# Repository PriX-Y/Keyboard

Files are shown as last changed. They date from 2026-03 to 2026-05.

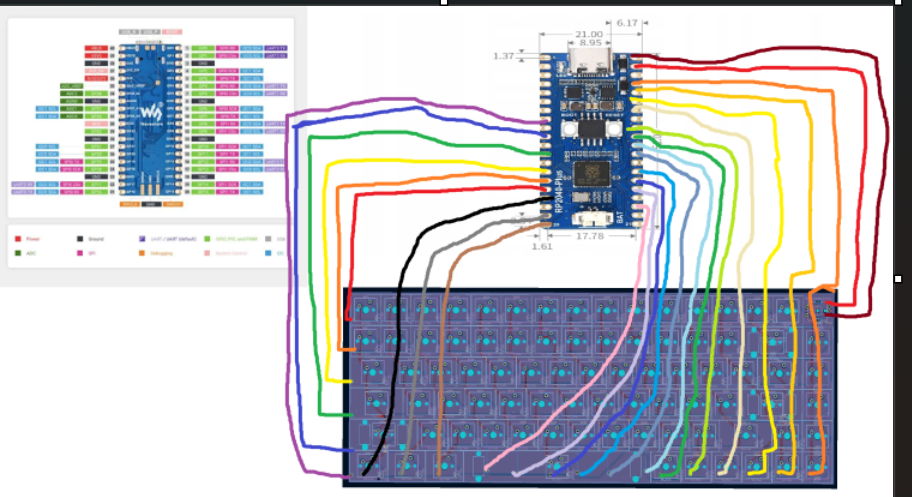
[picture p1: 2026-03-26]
Wiring Diagram.png

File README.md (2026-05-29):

# Befor. Im from Poland and im dont speak english very well , dont rate grammer :)

# HI. there is my keyboard
I made this becuse i need keyboard. my actualy keyboard is 12 years: cosaco keyboard what i need use hot glue to repeir what.

IMG_20260326_175041831_MFNR
IMG_20260326_175053504_MFNR

it still work but Bro . you see how this look , i dont say its bad keyboard for me is fine but i wanna make something own what i be use for next years.

# So there is my PKSBoard ( i dont have idea for name) 

1776988882284-g3whwp

**Note** im finnaly dont use case becuse i dont have budget left for printing legion

**It base on most simple things but becuse i wanna clean 65%+ i need to make Mcu and Key PCB separate**
 on key pcb you dont see rp2040 its becuse i separte it and is why pick 2.54mm right angle , cable, 

Zrzut ekranu 2026-03-27 213238

Zrzut ekranu 2026-03-27 213307

Zrzut ekranu 2026-02-13 215402

-**MCU:** RP2040-Plus ,  Everyone know wha t mcu is this.

-**PCB:** My own project , Is **65%** size keyboard but i add Function button and Rotery Encoder
Zrzut ekranu 2026-03-26 210054
old version
Zrzut ekranu 2026-03-14 180553

-**Switch:** Akko V3 creamy blue is one of best budget switch on the world. its tactical so is silent 
but you fell click

-**Keycaps.** any random chepest keycaps what i can find to fit in budget

-**Stablizators:** for keycaps

-**cable** just cable
there is cart

Zrzut ekranu 2026-03-26 194902

-**Diods:** i pick that becuse i have footprint only for this one

-**Connector:** to conect it its why is right angle
there is cart from tme

Zrzut ekranu 2026-03-24 231726

**Case:** is simple case what i made in Fusion , im not skilled in this so is why is a simple.

Zrzut ekranu 2026-03-23 025524

# **i use programs:**

**Kicad:** For PCB
**Autodesk** fusion: For 3D modeling
**Paint:** for diagram
**Google Docs:** For BOM
**Cursor:** for code

is all i spend aorund 20h on buldi this becuse i spend aorund 7h mcu what i finnaly dont buldi becuse cost. i have all in blueprint site so is why i dont have jounary here. finally my keyboard for me personal is good ( i be happy if it get aproved) 

# btw im pass this 

# there is one thing what left: BOM ( without link there, link verison is in folder)


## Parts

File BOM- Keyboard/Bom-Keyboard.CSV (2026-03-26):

Swicht Akko v3 creamy blue 45 pack | x2 | 29.12$ (14.56$ x2) | aliexprees | https://pl.aliexpress.com/item/1005006382591392.html?mp=1
Keyboard Pcb + ship + tax | x1 | 40.42$ | Jbpcb | https://jlcpcb.com/
1N4148W Diodes, Headers, Shipping | x1 | 10.31$ | tme.eu | https://www.tme.eu/pl/
rassbery pico - rp2040 plus | x1 | 6.76$ | aliexprees | https://pl.aliexpress.com/item/1005005655604927.html?mp=1
keyscaps stabilizator | x1 | 5.78$ | aliexprees | https://pl.aliexpress.com/item/1005001686299616.html?mp=1
keycaps - purple + dark | x1 | 4.01$ | aliexprees | https://pl.aliexpress.com/item/1005011904232892.html?mp=1
cable 20 pack F to F | x2 | 2.70$ (1.35$ x2) | aliexprees | https://pl.aliexpress.com/item/1005007138874742.html?mp=1
Total Cost: $99.10
I ask for 100$ if something left i give it back

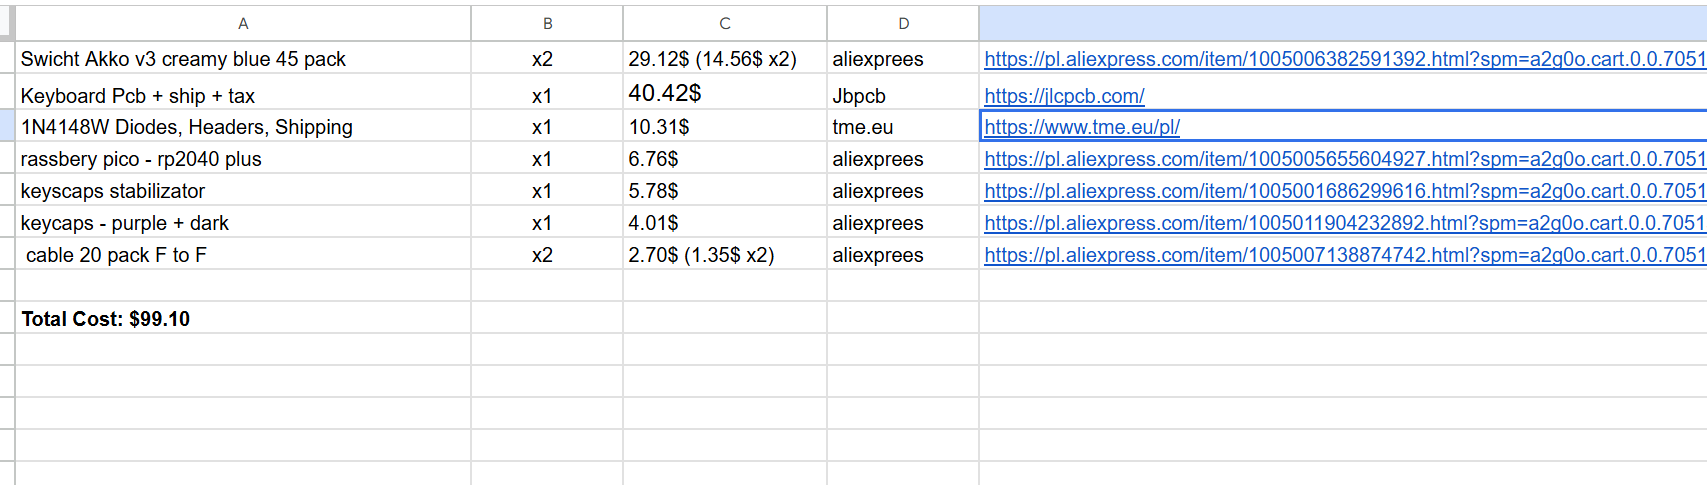
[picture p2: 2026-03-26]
BOM- Keyboard/BOM-Image.png

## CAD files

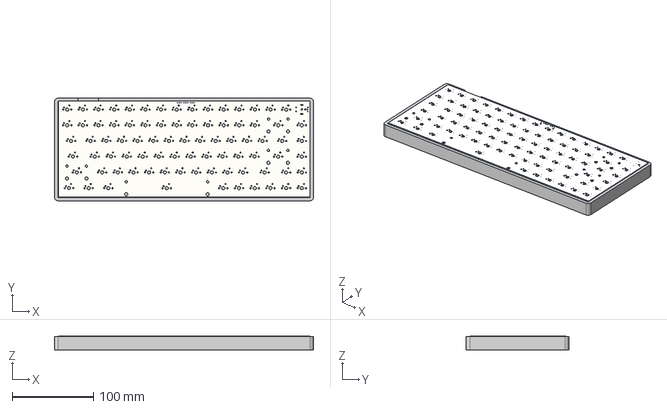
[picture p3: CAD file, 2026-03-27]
Keyboard-Assembly.step
318.0 x 126.0 x 17.4 mm

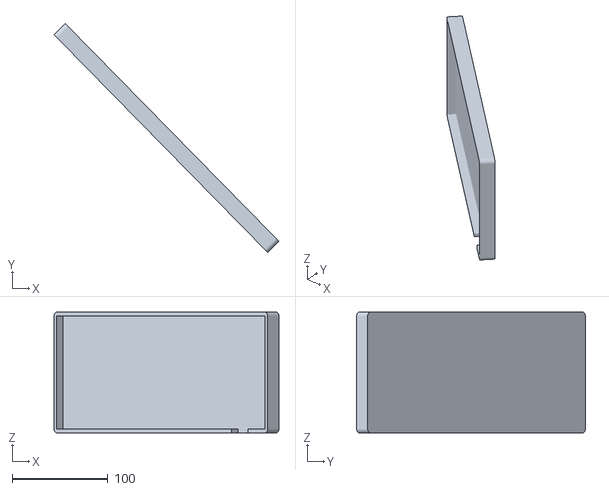
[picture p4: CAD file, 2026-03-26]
CAD file/Keyboard Case.step.stl
234.5 x 238.6 x 126.0

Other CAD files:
CAD file/Keyboard Case.3mf
CAD file/Keyboard Case.f3d

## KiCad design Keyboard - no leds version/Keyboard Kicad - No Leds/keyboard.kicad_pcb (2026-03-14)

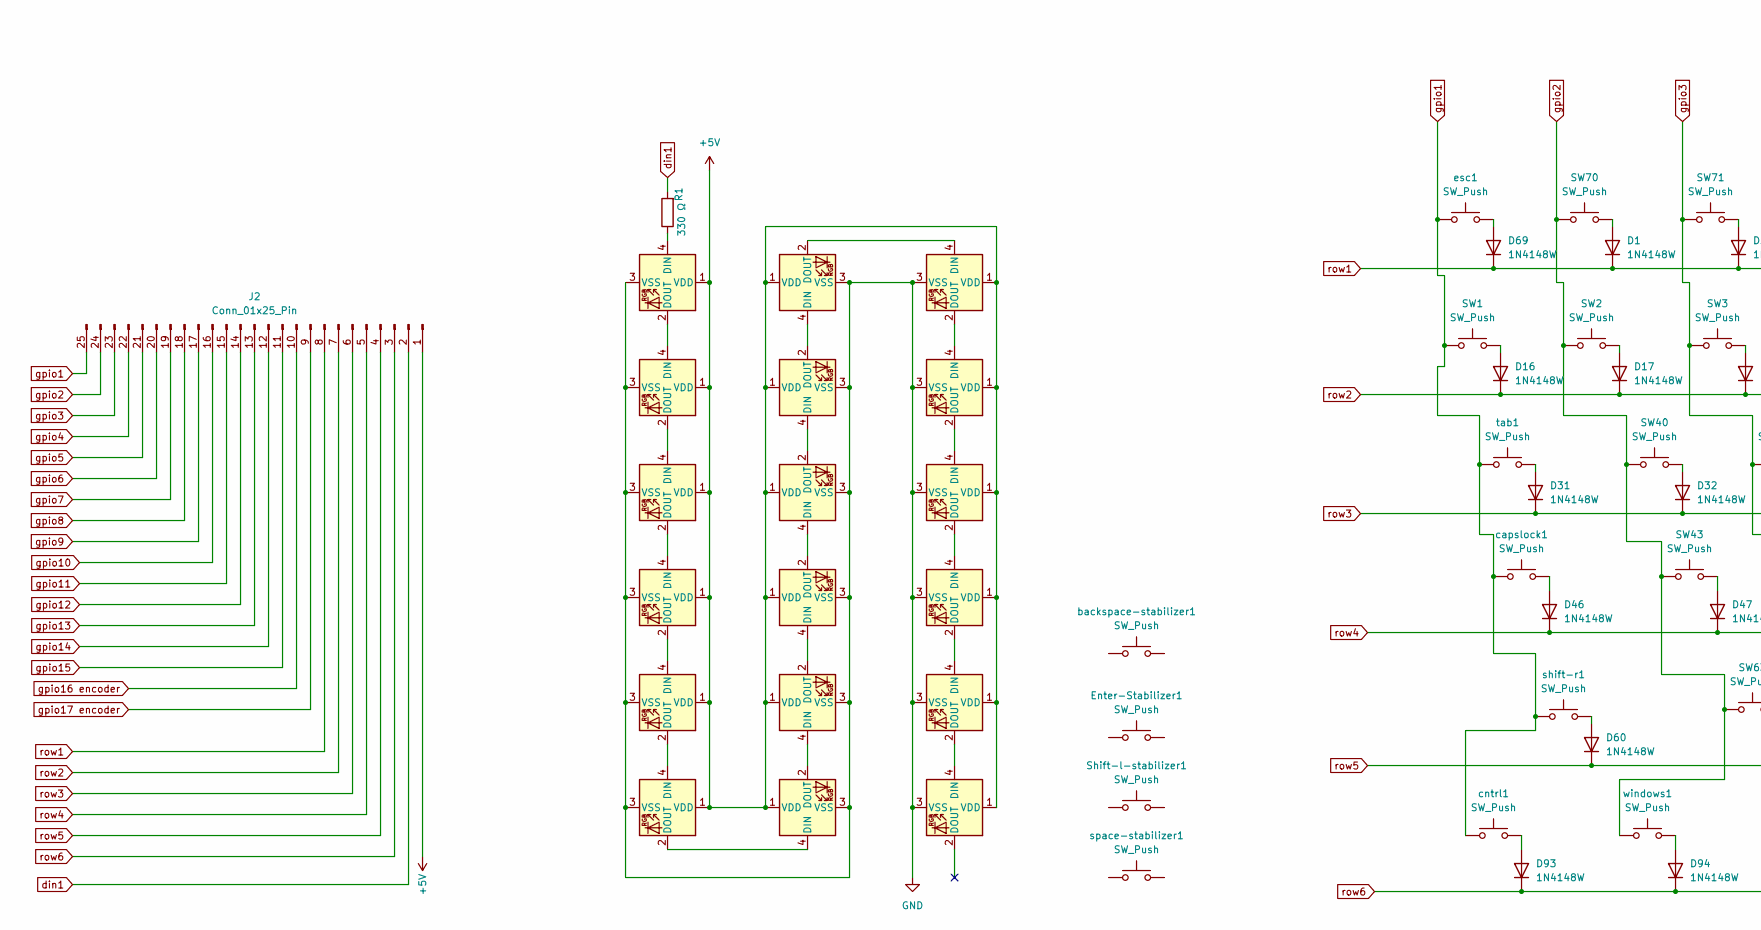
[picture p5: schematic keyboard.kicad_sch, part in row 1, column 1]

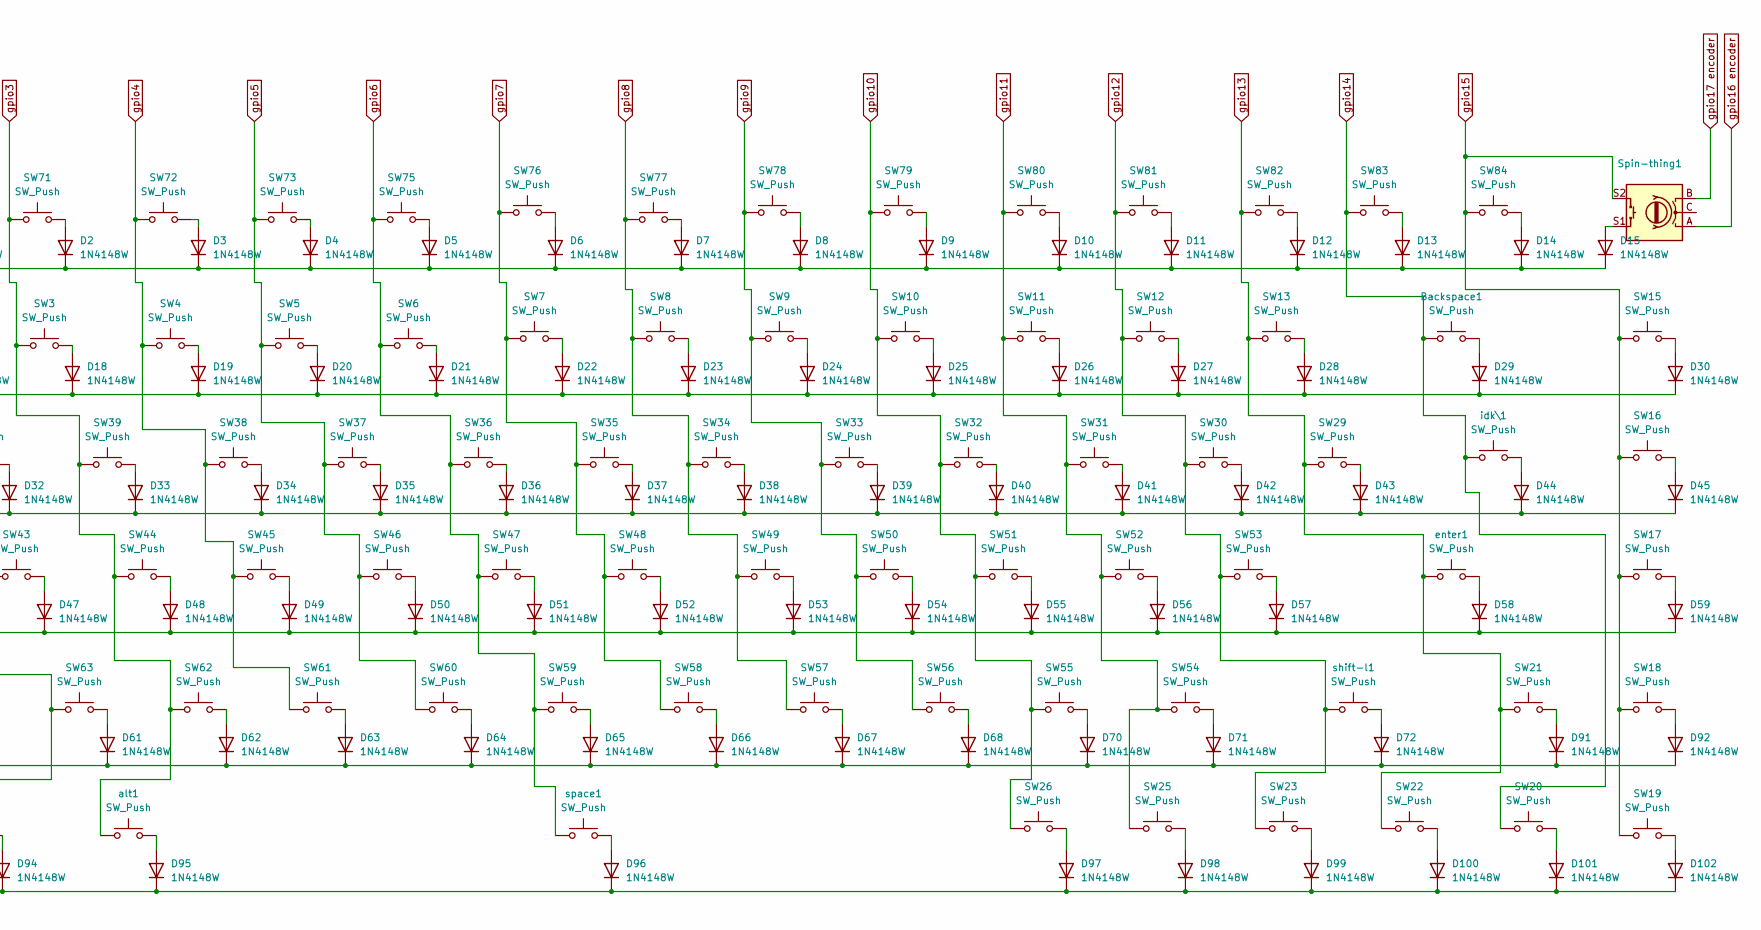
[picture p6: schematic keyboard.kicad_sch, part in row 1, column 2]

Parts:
Backspace1: SW_Push; SW_Cherry_MX_PCB_2.00u
D1, D2, D3, D4, D5, D6, D7, D8, D9, D10, D11, D12, D13, D14, D15, D16, D17, D18, D19, D20, D21, D22, D23, D24, D25, D26, D27, D28, D29, D30, D31, D32, D33, D34, D35, D36, D37, D38, D39, D40, D41, D42, D43, D44, D45, D46, D47, D48, D49, D50, D51, D52, D53, D54, D55, D56, D57, D58, D59, D60, D61, D62, D63, D64, D65, D66, D67, D68, D69, D70, D71, D72, D91, D92, D93, D94, D95, D96, D97, D98, D99, D100, D101, D102: 1N4148W; D_SOD-123
D73, D74, D75, D76, D77, D78, D79, D80, D81, D82, D83, D84, D85, D86, D87, D88, D89, D90: WS2812B; LED_WS2812B-Mini_PLCC4_3.5x3.5mm
Enter-Stabilizer1: SW_Push; Stabilizer_Cherry_MX_2.00u
J2: Conn_01x25_Pin; PinHeader_1x25_P1.00mm_Vertical
R1: 330 Ω; R_0805_2012Metric_Pad1.20x1.40mm_HandSolder
SW1, SW2, SW3, SW4, SW5, SW6, SW7, SW8, SW9, SW10, SW11, SW12, SW13, SW15, SW16, SW17, SW18, SW19, SW20, SW21, SW22, SW23, SW25, SW26, SW29, SW30, SW31, SW32, SW33, SW34, SW35, SW36, SW37, SW38, SW39, SW40, SW43, SW44, SW45, SW46, SW47, SW48, SW49, SW50, SW51, SW52, SW53, SW54, SW55, SW56, SW57, SW58, SW59, SW60, SW61, SW62, SW63, SW70, SW71, SW72, SW73, SW75, SW76, SW77, SW78, SW79, SW80, SW81, SW82, SW83, SW84: SW_Push; SW_Cherry_MX_PCB_1.00u
Shift-l-stabilizer1: SW_Push; Stabilizer_Cherry_MX_2.00u
Spin-thing1: RotaryEncoder_Switch; RotaryEncoder_Alps_EC11E-Switch_Vertical_H20mm_MountingHoles
alt1: SW_Push; SW_Cherry_MX_PCB_1.25u
backspace-stabilizer1: SW_Push; Stabilizer_Cherry_MX_2.00u
capslock1: SW_Push; SW_Cherry_MX_PCB_1.75u
cntrl1: SW_Push; SW_Cherry_MX_PCB_1.25u
enter1: SW_Push; SW_Cherry_MX_PCB_2.00u
esc1: SW_Push; SW_Cherry_MX_PCB_1.00u
idk\1: SW_Push; SW_Cherry_MX_PCB_1.50u
shift-l1: SW_Push; SW_Cherry_MX_PCB_1.75u
shift-r1: SW_Push; SW_Cherry_MX_PCB_2.25u
space1: SW_Push; SW_Cherry_MX_PCB_6.25u
space-stabilizer1: SW_Push; Stabilizer_Cherry_MX_6.25u
tab1: SW_Push; SW_Cherry_MX_PCB_1.50u
windows1: SW_Push; SW_Cherry_MX_PCB_1.25u

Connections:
+5V: D73.1 (VDD), D74.1 (VDD), D75.1 (VDD), D76.1 (VDD), D77.1 (VDD), D78.1 (VDD), D79.1 (VDD), D80.1 (VDD), D81.1 (VDD), D82.1 (VDD), D83.1 (VDD), D84.1 (VDD), D85.1 (VDD), D86.1 (VDD), D87.1 (VDD), D88.1 (VDD), D89.1 (VDD), D90.1 (VDD), J2.1
unnamed: D1.2 (A), SW70.2
unnamed: D2.2 (A), SW71.2
unnamed: D3.2 (A), SW72.2
unnamed: D4.2 (A), SW73.2
unnamed: D5.2 (A), SW75.2
unnamed: D6.2 (A), SW76.2
unnamed: D7.2 (A), SW77.2
unnamed: D8.2 (A), SW78.2
unnamed: D9.2 (A), SW79.2
unnamed: D10.2 (A), SW80.2
unnamed: D11.2 (A), SW81.2
unnamed: D12.2 (A), SW82.2
unnamed: D13.2 (A), SW83.2
unnamed: D14.2 (A), SW84.2
unnamed: D15.2 (A), Spin-thing1.S1
unnamed: D16.2 (A), SW1.2
unnamed: D17.2 (A), SW2.2
unnamed: D18.2 (A), SW3.2
unnamed: D19.2 (A), SW4.2
unnamed: D20.2 (A), SW5.2
unnamed: D21.2 (A), SW6.2
unnamed: D22.2 (A), SW7.2
unnamed: D23.2 (A), SW8.2
unnamed: D24.2 (A), SW9.2
unnamed: D25.2 (A), SW10.2
unnamed: D26.2 (A), SW11.2
unnamed: D27.2 (A), SW12.2
unnamed: D28.2 (A), SW13.2
unnamed: Backspace1.2, D29.2 (A)
unnamed: D30.2 (A), SW15.2
unnamed: D31.2 (A), tab1.2
unnamed: D32.2 (A), SW40.2
unnamed: D33.2 (A), SW39.2
unnamed: D34.2 (A), SW38.2
unnamed: D35.2 (A), SW37.2
unnamed: D36.2 (A), SW36.2
unnamed: D37.2 (A), SW35.2
unnamed: D38.2 (A), SW34.2
unnamed: D39.2 (A), SW33.2
unnamed: D40.2 (A), SW32.2
unnamed: D41.2 (A), SW31.2
unnamed: D42.2 (A), SW30.2
unnamed: D43.2 (A), SW29.2
unnamed: D44.2 (A), idk\1.2
unnamed: D45.2 (A), SW16.2
unnamed: D46.2 (A), capslock1.2
unnamed: D47.2 (A), SW43.2
unnamed: D48.2 (A), SW44.2
unnamed: D49.2 (A), SW45.2
unnamed: D50.2 (A), SW46.2
unnamed: D51.2 (A), SW47.2
unnamed: D52.2 (A), SW48.2
unnamed: D53.2 (A), SW49.2
unnamed: D54.2 (A), SW50.2
unnamed: D55.2 (A), SW51.2
unnamed: D56.2 (A), SW52.2
unnamed: D57.2 (A), SW53.2
unnamed: D58.2 (A), enter1.2
unnamed: D59.2 (A), SW17.2
unnamed: D60.2 (A), shift-r1.2
unnamed: D61.2 (A), SW63.2
unnamed: D62.2 (A), SW62.2
unnamed: D63.2 (A), SW61.2
unnamed: D64.2 (A), SW60.2
unnamed: D65.2 (A), SW59.2
unnamed: D66.2 (A), SW58.2
unnamed: D67.2 (A), SW57.2
unnamed: D68.2 (A), SW56.2
unnamed: D69.2 (A), esc1.2
unnamed: D70.2 (A), SW55.2
unnamed: D71.2 (A), SW54.2
unnamed: D72.2 (A), shift-l1.2
unnamed: D73.2 (DOUT), D74.4 (DIN)
unnamed: D73.3 (VSS), D74.3 (VSS), D75.3 (VSS), D76.3 (VSS), D77.3 (VSS), D78.3 (VSS), D79.3 (VSS), D80.3 (VSS), D81.3 (VSS), D82.3 (VSS), D83.3 (VSS), D84.3 (VSS), D85.3 (VSS), D86.3 (VSS), D87.3 (VSS), D88.3 (VSS), D89.3 (VSS), D90.3 (VSS)
unnamed: D73.4 (DIN), R1.1
unnamed: D74.2 (DOUT), D75.4 (DIN)
unnamed: D75.2 (DOUT), D76.4 (DIN)
unnamed: D76.2 (DOUT), D77.4 (DIN)
unnamed: D77.2 (DOUT), D78.4 (DIN)
unnamed: D78.2 (DOUT), D79.4 (DIN)
unnamed: D79.2 (DOUT), D80.4 (DIN)
unnamed: D80.2 (DOUT), D81.4 (DIN)
unnamed: D81.2 (DOUT), D82.4 (DIN)
unnamed: D82.2 (DOUT), D83.4 (DIN)
unnamed: D83.2 (DOUT), D84.4 (DIN)
unnamed: D84.2 (DOUT), D90.4 (DIN)
unnamed: D85.4 (DIN), D86.2 (DOUT)
unnamed: D86.4 (DIN), D87.2 (DOUT)
unnamed: D87.4 (DIN), D88.2 (DOUT)
unnamed: D88.4 (DIN), D89.2 (DOUT)
unnamed: D89.4 (DIN), D90.2 (DOUT)
unnamed: D91.2 (A), SW21.2
unnamed: D92.2 (A), SW18.2
unnamed: D93.2 (A), cntrl1.2
unnamed: D94.2 (A), windows1.2
unnamed: D95.2 (A), alt1.2
unnamed: D96.2 (A), space1.2
unnamed: D97.2 (A), SW26.2
unnamed: D98.2 (A), SW25.2
unnamed: D99.2 (A), SW23.2
unnamed: D100.2 (A), SW22.2
unnamed: D101.2 (A), SW20.2
unnamed: D102.2 (A), SW19.2
din1: J2.2, R1.2
gpio1: J2.25, SW1.1, capslock1.1, cntrl1.1, esc1.1, shift-r1.1, tab1.1
gpio2: J2.24, SW2.1, SW40.1, SW43.1, SW63.1, SW70.1, windows1.1
gpio3: J2.23, SW3.1, SW39.1, SW44.1, SW62.1, SW71.1, alt1.1
gpio4: J2.22, SW4.1, SW38.1, SW45.1, SW61.1, SW72.1
gpio5: J2.21, SW5.1, SW37.1, SW46.1, SW60.1, SW73.1
gpio6: J2.20, SW6.1, SW36.1, SW47.1, SW59.1, SW75.1, space1.1
gpio7: J2.19, SW7.1, SW35.1, SW48.1, SW58.1, SW76.1
gpio8: J2.18, SW8.1, SW34.1, SW49.1, SW57.1, SW77.1
gpio9: J2.17, SW9.1, SW33.1, SW50.1, SW56.1, SW78.1
gpio10: J2.16, SW10.1, SW26.1, SW32.1, SW51.1, SW55.1, SW79.1
gpio11: J2.15, SW11.1, SW25.1, SW31.1, SW52.1, SW54.1, SW80.1
gpio12: J2.14, SW12.1, SW23.1, SW30.1, SW53.1, SW81.1, shift-l1.1
gpio13: J2.13, SW13.1, SW21.1, SW22.1, SW29.1, SW82.1, enter1.1
gpio14: Backspace1.1, J2.12, SW20.1, SW83.1, idk\1.1
gpio15: J2.11, SW15.1, SW16.1, SW17.1, SW18.1, SW19.1, SW84.1, Spin-thing1.S2
gpio16 encoder: J2.10, Spin-thing1.A
gpio17 encoder: J2.9, Spin-thing1.B
row1: D1.1 (K), D2.1 (K), D3.1 (K), D4.1 (K), D5.1 (K), D6.1 (K), D7.1 (K), D8.1 (K), D9.1 (K), D10.1 (K), D11.1 (K), D12.1 (K), D13.1 (K), D14.1 (K), D15.1 (K), D69.1 (K), J2.8
row2: D16.1 (K), D17.1 (K), D18.1 (K), D19.1 (K), D20.1 (K), D21.1 (K), D22.1 (K), D23.1 (K), D24.1 (K), D25.1 (K), D26.1 (K), D27.1 (K), D28.1 (K), D29.1 (K), D30.1 (K), J2.7
row3: D31.1 (K), D32.1 (K), D33.1 (K), D34.1 (K), D35.1 (K), D36.1 (K), D37.1 (K), D38.1 (K), D39.1 (K), D40.1 (K), D41.1 (K), D42.1 (K), D43.1 (K), D44.1 (K), D45.1 (K), J2.6
row4: D46.1 (K), D47.1 (K), D48.1 (K), D49.1 (K), D50.1 (K), D51.1 (K), D52.1 (K), D53.1 (K), D54.1 (K), D55.1 (K), D56.1 (K), D57.1 (K), D58.1 (K), D59.1 (K), J2.5
row5: D60.1 (K), D61.1 (K), D62.1 (K), D63.1 (K), D64.1 (K), D65.1 (K), D66.1 (K), D67.1 (K), D68.1 (K), D70.1 (K), D71.1 (K), D72.1 (K), D91.1 (K), D92.1 (K), J2.4
row6: D93.1 (K), D94.1 (K), D95.1 (K), D96.1 (K), D97.1 (K), D98.1 (K), D99.1 (K), D100.1 (K), D101.1 (K), D102.1 (K), J2.3

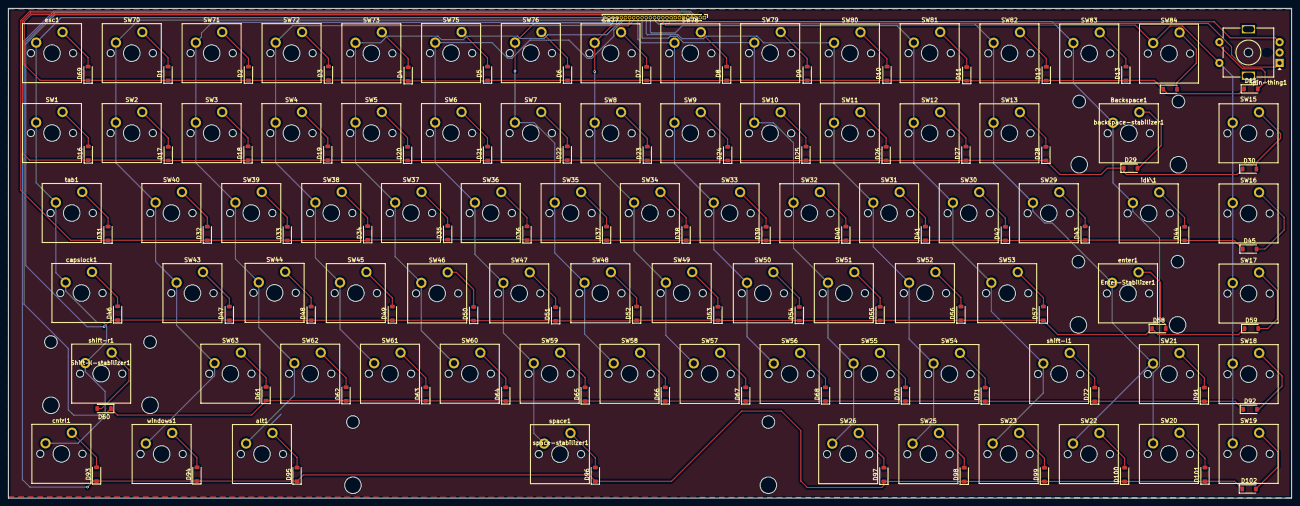
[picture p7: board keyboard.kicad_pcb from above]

Board: 2 copper layers, 308.9 x 117.9 mm, 173 parts (0 on the bottom side), 107 nets.
